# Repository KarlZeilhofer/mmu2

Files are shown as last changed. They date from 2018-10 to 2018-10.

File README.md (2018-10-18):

DIY Multi Material Upgrade V2.0
==========================
firmware clone project
--------------------------------

This code was developed on an Arduino Mega board using three 8825 stepper motors to control the MMU2 multi-color print head. 
It was designed to operate with the PRUSA mk3 printer.  This code was developed to replace the stock MMU2 controller board, I got bored so I decided to create my own design.  Getting it to play nicely with the mk3 was quite a challenge.  This home brew MMU2 only will operate with the MK3 currently.

You will need an Arduino Mega 2560 processor board and a RAMPS 1.5 or RAMPS 1.6 shield (for the stepper motor controllers) - both are available on Amazon (see my BOM for additional details)

A serial cable is required (5 pin) in order to communicate between this board and the Mk3 controller.  (Vcc, Tx, Rx, GND, Reset).  Only 3 pins are required (Tx, Rx and Reset) in order to work properly with the Mk3.

## WARNING:  
This project is a work in progress and requires a knowledge of Mk3 hardware and software.  If you don't know what you are doing, you can/will PERMANENTLY damage your hardware.  I hope you have been appropriately warned.
          
## ADDITIONAL WARNING
you probably won't read this because it is too far down the page:

**Stepper Motor controllers (8825) are high current devices and they get warm/hot.  You can damage these controller easily
(I have) if you don't adjust the source current.  There is a very small variable resister you will have to adjust, I 
recommend setting this to 0.6V (details on how to adjust this are on the polulu.com website - look for 8825 stepper 
motor controller).  If you don't have a multimeter for measuring voltage then STOP - you are in deep waters.**

## Build Instructions
This project is made to be built either with the Arduino IDE or with Platformio. And both boards - Arduino Mega (DIY build) and Leonardo (official Prusa controller board) are supported. The later one is still work in progress. 

### Arduino
Tested with Arduino IDE 1.8.5. Open the file ./mmu2-diy/mmu2-diy.ino in your Arduino IDE, select your board and hit compile and upload.

### Platformio
You may adjust the the board in the platformio.ini file before running these lines:
```
pio init
pio run
pio run --target upload
```

## TODOs
* Document Pinouts for each of the stepper motors
* Document Pinouts for 2 sensor cables
* Document Pinouts for Cable between MMU2 controller and MK3 controller (TX, RX, Reset, Vcc)

### Official MMU Controller Board
* Define correct pins
  * Step signals 1-3
  * Push buttons (analog input)
  * stall detection inputs
  * Shift register (data, clock, latch)
    for Dir 1-3, Enable 1-3, LEDs (5x green, 5x red)
  * chip selects for stepper drivers
  * finda probe
* Initialize stepper drivers
* write shift register code

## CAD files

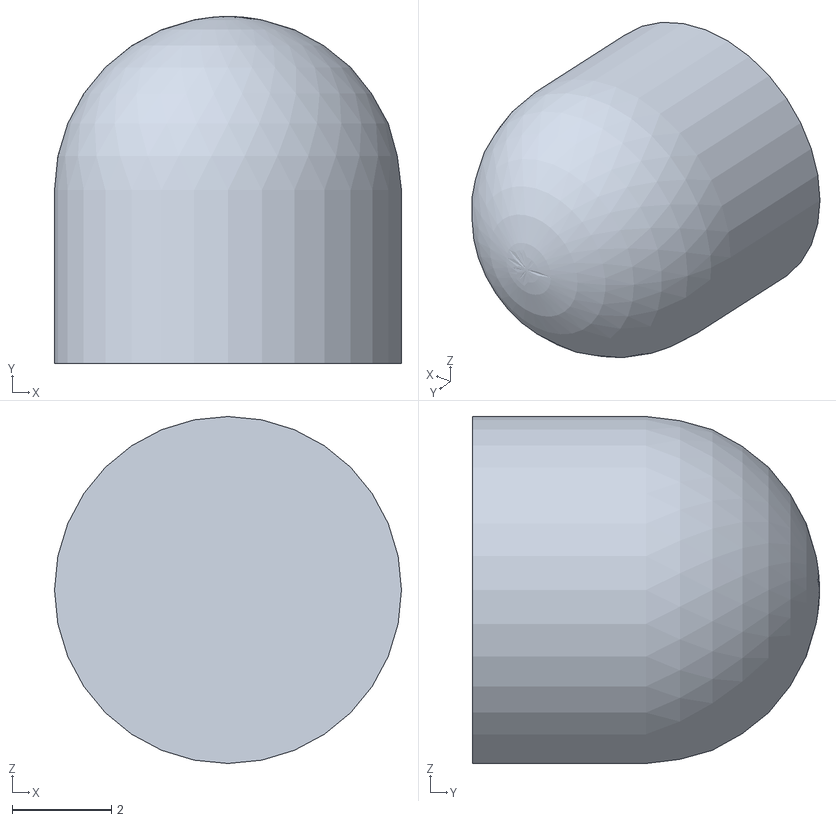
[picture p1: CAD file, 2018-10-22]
stls/filament-piston-7mm.stl
7.00 x 7.00 x 7.00

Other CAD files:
stls/filament-piston.fcstd

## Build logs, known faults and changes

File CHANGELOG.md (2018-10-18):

Changelog for DIY MMU 2.0
=========================

# 2018-10-18
* refactored repository
* restructured folders and filenames
* add platformio.ini
* add wrapper class Application for compatibility with
  Arduino IDE and Platformio with QtCreator.
  Tested compiling with Arduino IDE 1.8.5
* reduced RAM usage using progmem macro F() from 139% to 45%
  for Arduino Leonardo
* add config.h
* fixed all compiler warnings. Some were critical with integer overflow!
  (works with all config flags in config.h enabled or disabled)
* add Axis class
* add defs.h
* use macros SerialUI and SerialPrinter for better clarity
* put shift register and native pins into a single number space using pinWrite()
*

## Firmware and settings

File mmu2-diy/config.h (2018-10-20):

#ifndef CONFIG_H
#define CONFIG_H

#include <stdint.h>

#define MMU2_VERSION "0.5.0  2018-10-18"
#define FW_VERSION 50             // config.h  (MM-control-01 firmware)
#define FW_BUILDNR 85             // config.h  (MM-control-01 firmware)

//#define DEBUG
//#define DEBUGIDLER
//#define NOTDEF
//#define CRAZYIVAN
//#define TURNOFFSELECTORMOTOR

//#define DIY_BOARD
#define PRUSA_BOARD

#define TEST_LEDs // successfully tested
#define TEST_AXIS

#endif // CONFIG_H

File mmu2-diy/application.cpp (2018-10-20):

// CSK MMU2 Controller Version
//
//  Code developed by Chuck Kozlowski
//  September 19, 2018
//
//  Code was developed because I am impatiently waiting for my MMU2 to arrive (due in December, 2018) so I thought
//  I would develop some code to operate the PRUSA MMU2 hardware
//
// This code uses 3 stepper motor controllers and 1 Pinda filament sensor, and 1 additional filament sensor on the mk3 extruder top
//
//
//  Work to be done:  Interface Control with the Einsy Board (MK3) - (work completed on 9.25.18)
//                    Refine speed and acceleration settings for each stepper motor
//                    Failure Recovery Modes - basically non-existent (work completed on 10.5.18)
//
//                    Uses the serial interface with a host computer at the moment - probably could do some smarter things
//                                                                                   like selection switches and some LEDs.
//                   10.14.18 Leave the Selector Stepper Motor ON ... appear to be losing position with the selector during operation
//                            [now using the J-4218HB2301 Stepper Motor - (45 N-cm torque) as the idler stepper motor]
//                   10.14.18 Added yet another idler command set (specialparkidler() and specialunparkidler) - used within the 'C' Command
//                            Idler management is a bit of challenge,  probably has more to do with my coding skills (or lack thereof).
//                   10.12.18 Minor fix to idler parking ... now use quickparkidler() after 'C' command and quickunparkidler() at beginning of 'T' command
//                              This helps to speed up the idler movements during 'T' and 'C' commands
//                   10.5.18  Made major tweak to the 'C' command, now matches the speed of the mk3 extruder gear (see slic3r 'load' setting)
//                   10.2.18  Moved from breadboard to RAMPS 1.6 Board and remapped ALL addresses
//                            Discovered the filament idler motor needed to be set at a higher torque (more current)
//                            (this was affected filament load consistency)
//                   10.2.18  Major Disaster, lost my codebase on my PC (I am an idiot)
//                            Thank God for github so I could recover a week old version of my code
//                   10.1.18  Added filament sensor to the extruder head (helps reliability


//#include <SoftwareSerialUI.h>
#include <Arduino.h>
#include <stdio.h>
#include <string.h>
#include <stdarg.h>
#include "application.h"
#include "config.h"
#include "axis.h"

#ifdef PRUSA_BOARD
#include "shiftregister.h"
#endif

static int isFilamentLoaded();
static void initIdlerPosition();
static void checkSerialInterface();
static void initColorSelector();
static void filamentLoadWithBondTechGear();
static void toolChange( char selection);
static void quickUnParkIdler();
static void unParkIdler();
static void unloadFilamentToFinda();
static void parkIdler();
static void activateColorSelector();
static void idlerSelector(char filament);
static void colorSelector(char selection);
static void loadFilamentToFinda();
static void fixTheProblem(String statement);
static void csTurnAmount(int steps, int direction);
static void feedFilament(unsigned int steps);


#define SERIAL1ENABLED    1


#define STEPSPERMM  144ul           // these are the number of steps required to travel 1 mm using the extruder motor


#define ORIGINALCODE 0            // code that is no longer needed for operational use
int command = 0;

// changed from 125 to 115 (10.13.18)
#define MAX_IDLER_STEPS 125         // number of steps that the roller bearing stepper motor can travel, in full steps
#define MAXSELECTOR_STEPS   1890   // maximum number of selector stepper motor (used to move all the way to the right or left, in full steps



#define MMU2TOEXTRUDERSTEPS STEPSIZE*STEPSPERREVOLUTION*19   // for the 'T' command 


#define INACTIVE 0                           // used for 3 states of the idler stepper motor (parked)
#define ACTIVE 1                             // not parked 
#define QUICKPARKED 2                            // quick parked


//************************************************************************************
//* this resets the selector stepper motor after the selected number of tool changes
//* changed from 25 to 10 (10.10.18)
//* chagned from 10 to 8 (10.14.18)
//*************************************************************************************
#define TOOLSYNC 20                         // number of tool change (T) commands before a selector resync is performed



// the MMU2 currently runs at 21mm/sec (set by Slic3r) for 2 seconds (good stuff to know)
//
// the load duration was chagned from 1 second to 1.1 seconds on 10.8.18 (as an experiment)
// increased from 1.1 to 1.5 seconds on 10.13.18 (another experiment)
#define LOAD_DURATION 1600                 // duration of 'C' command during the load process (in milliseconds)


// changed from 21 mm/sec to 30 mm/sec on 10.13.18
#define LOAD_SPEED 30                   // load speed (in mm/second) during the 'C' command (determined by Slic3r setting)



#define IDLERSTEPSIZE 23         // full steps to each roller bearing
//float bearingAbsPos[5] = {1, 24, 48, 72, 96}; // absolute position of roller bearing stepper motor
float bearingAbsPos[5] = {0, IDLERSTEPSIZE, IDLERSTEPSIZE * 2, IDLERSTEPSIZE * 3, IDLERSTEPSIZE * 4};



// changed position #2 to 372  (still tuning this little sucker)


#define CSSTEPS 357                        //                                                 
int selectorAbsPos[5] = {0, CSSTEPS * 1, CSSTEPS * 2, CSSTEPS * 3, CSSTEPS * 4}; // absolute position of selector stepper motor


int trackToolChanges = 0;
int extruderMotorStatus = INACTIVE;


int currentCSPosition = 0;         // color selector position
int currentPosition = 0;

int repeatTCmdFlag =
    INACTIVE;    // used by the 'C' command processor to avoid processing multiple 'C' commands

int oldBearingPosition = 0;      // this tracks the roller bearing position (top motor on the MMU)
int filamentSelection = 0;       // keep track of filament selection (0,1,2,3,4))
int dummy[100];
char currentExtruder = '0';

int firstTimeFlag = 0;
int earlyCommands = 0;           // forcing communications with the mk3 at startup

int toolChangeCount = 0;

char receivedChar;
boolean newData = false;
int idlerStatus = INACTIVE;
int colorSelectorStatus = INACTIVE;

#ifdef PRUSA_BOARD
ShiftRegister extPins(16, 9, 13, 10);
#endif
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

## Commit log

2018-10-18 fix all compiler warnings, add config.h
    [application.cpp, config.h]
2018-10-18 replaced switch-case by if-statement
    [application.cpp]
2018-10-18 work in progress, compiles without errors/warnings
    [application.cpp, axis.h, config.h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]
2018-10-20 implemented and tested LEDs on shift register, ...
    further coding on class Axis
2018-10-22 add CAD of 7mm piston for sensing filament with micro switch
    [filament-piston-7mm.stl, filament-piston.fcstd]
